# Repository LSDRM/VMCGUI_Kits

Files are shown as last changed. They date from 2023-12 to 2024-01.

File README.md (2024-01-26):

Resources for [VMCGUI](https://github.com/LSDRM/VMCGUI)
===============
----------
## Kits
### Arduino based :
No arduino based kit has been developed yet.

### Customized :
- [DualPressure - Thermocouple / through UART protocol](https://github.com/LSDRM/DualPressure-Thermocouple_forVMCGUI) : A DAQ board embeding two pressure sensors and one thermocouple. Developed by @B137P107

### Raspberry Pi based :
No raspberry pi based kit has been developed yet.

-------
## Modules
- [USB to UART bridge](https://github.com/LSDRM/USBtoUART-module_forVMCGUI) : To allow a computer the communicate through an UART communication line, via its USB port. Developed by @B137P107
--------

Make your own kit
=============
This repository include a _#BlankKit.py_ file which is a base to start making your own kit, working with VMCGUI. Making your own kit requires a bit of electronical knowledge, especially if you want to do it by making your own DAQ board (i.e. without an Arduino or other ready-to-use DAQ board). Creating a new kit implies software and hardware development, the both parts are described below.

Software development
-----------
You should only need to make a python kit file from the _#BlankKit.py_, without modifying any file from the source code of VMCGUI. The latter file need to be renamed with the name you want to give it, and placed in the "APP/Kits" folder of the VMCGUI repository. Note that the _#_ right before the name of your file set this kit as inactive, so  VMCGUI will ignore it.

At the top of your kit file, you should find the imported packages. This is where you can call new packages for your application. For example, you can call `import pyfirmata` if you know your kit is an Arduino-based one using an USB connection.

The first method of the main class contained in the kit file is the `__init__` one. In this class, you should find parameters for your kit as described below :
- `self.setWindowTitle()` : Put between the brackets the title of the window for your kit in string format.
- `self.prefix` : This parameter take a string, which gonna be placed right before the default name of the recorded files.
- `self.closeStartWindowOnLaunch` : Is set to `True` by default to prevent opening multiple times the same Kit Window, which risks to create conflict between multiple windows calling the same connection port.
- `self.graphTitle` : Is a list of strings containing the name of each sensor present with the DAQ board.
- `self.sensorsNumber` : Shall not be modified since it need to correspond the number of sensors name in `self.graphTitle`.
- `self.GPIOsNumber` : Take the number of accessible GPIOs on the DAQ board.

Hardware development
-----------
### Arduino

### Customized

### Raspberry Pi

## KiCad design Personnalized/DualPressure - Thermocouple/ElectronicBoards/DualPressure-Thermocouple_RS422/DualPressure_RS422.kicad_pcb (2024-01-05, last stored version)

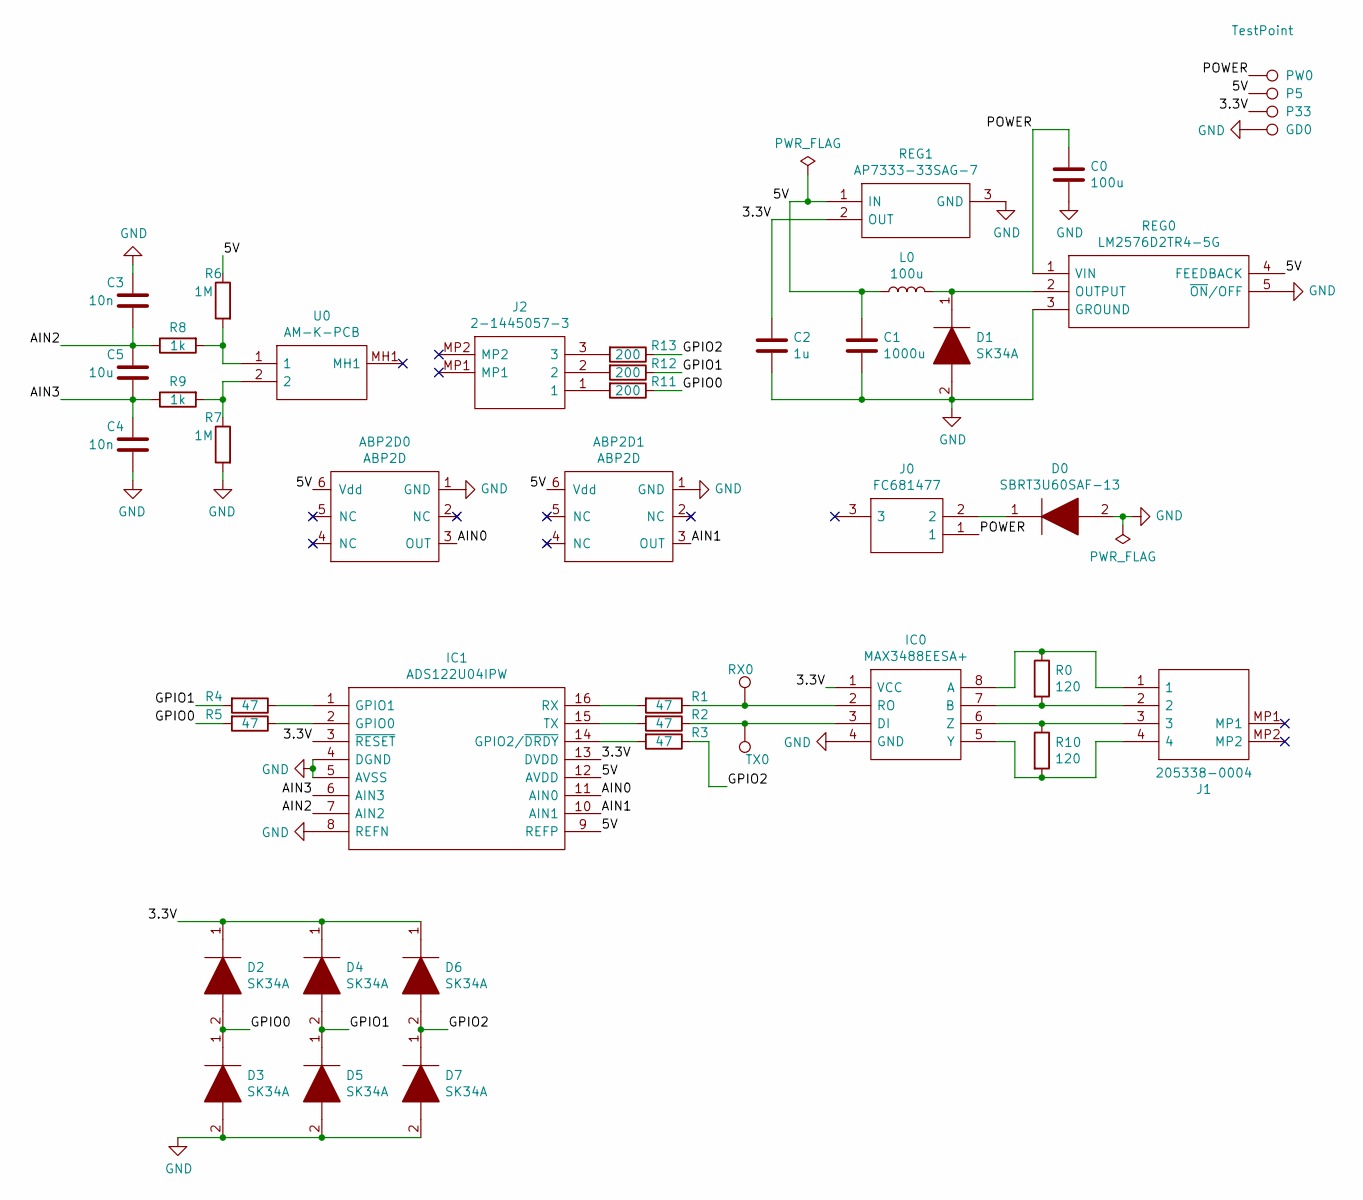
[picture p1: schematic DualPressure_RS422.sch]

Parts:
ABP2D0, ABP2D1: ABP2D
C0: 100u; CP_Elec_8x10.5
C1: 1000u; CP_Elec_10x10.5
C2: 1u; C_0603_1608Metric_Pad1.08x0.95mm_HandSolder
C3, C4: 10n; C_1206_3216Metric_Pad1.33x1.80mm_HandSolder
C5: 10u; C_1206_3216Metric_Pad1.33x1.80mm_HandSolder
D0: SBRT3U60SAF-13; SODFL5226X110N; Mouser Part Number 621-SBRT3U60SAF-13
D1, D2, D3, D4, D5, D6, D7: SK34A; DIOM5126X230N; Mouser Part Number 821-SK34A
GD0: TestPoint; TestPoint_THTPad_2.5x2.5mm_Drill1.2mm
IC0: MAX3488EESA+; SOIC127P600X175-8N; Mouser Part Number 700-MAX3488EESA
IC1: ADS122U04IPW; SOP65P640X120-16N; Mouser Part Number 595-ADS122U04IPW
J0: FC681477; Manufacturer_Part_Number FC681477
J1: 205338-0004; 2053380004; Manufacturer_Part_Number 205338-0004; Mouser Part Number 538-205338-0004
J2: 2-1445057-3; 214450573; Mouser Part Number 571-2-1445057-3
L0: 100u; L_0805_2012Metric_Pad1.15x1.40mm_HandSolder
P5, P33: TestPoint; TestPoint_THTPad_D2.5mm_Drill1.2mm
PW0: TestPoint; TestPoint_THTPad_D2.5mm_Drill1.2mm
R0, R10: 120; R_0805_2012Metric_Pad1.20x1.40mm_HandSolder
R1, R2, R3, R4, R5: 47; R_0805_2012Metric_Pad1.20x1.40mm_HandSolder
R6, R7: 1M; R_0805_2012Metric_Pad1.20x1.40mm_HandSolder
R8, R9: 1k; R_0805_2012Metric_Pad1.20x1.40mm_HandSolder
R11, R12, R13: 200; R_0805_2012Metric_Pad1.15x1.40mm_HandSolder
REG0: LM2576D2TR4-5G; D2TSUFFIX-CASE936A-02-ISSUEC; Mouser Part Number 863-LM2576D2TR4-5G
REG1: AP7333-33SAG-7; SOT96P240X135-3N; Mouser Part Number 621-AP7333-33SAG-7
RX0: TestPoint; TestPoint_THTPad_D2.5mm_Drill1.2mm
TX0: TestPoint; TestPoint_THTPad_D2.5mm_Drill1.2mm
U0: AM-K-PCB; AMKPCB; Manufacturer_Part_Number AM-K-PCB

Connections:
/3.3V: C2.1, D2.1, D4.1, D6.1, IC0.1 (VCC), IC1.3 (~RESET), IC1.13 (DVDD), P33.1, REG1.2 (OUT)
/5V: ABP2D0.6 (Vdd), ABP2D1.6 (Vdd), C1.1, IC1.9 (REFP), IC1.12 (AVDD), L0.1, P5.1, R6.1, REG0.4 (FEEDBACK), REG1.1 (IN)
/AIN0: ABP2D0.3 (OUT), IC1.11 (AIN0)
/AIN1: ABP2D1.3 (OUT), IC1.10 (AIN1)
/AIN2: C3.2, C5.1, IC1.7 (AIN2), R8.1
/AIN3: C4.1, C5.2, IC1.6 (AIN3), R9.1
/GPIO0: D2.2, D3.1, R5.2, R11.1
/GPIO1: D4.2, D5.1, R4.2, R12.1
/GPIO2: D6.2, D7.1, R3.1, R13.1
/POWER: C0.1, J0.1, PW0.1, REG0.1 (VIN)
GND: ABP2D0.1 (GND), ABP2D1.1 (GND), C0.2, C1.2, C2.2, C3.1, C4.2, D0.2, D1.2, D3.2, D5.2, D7.2, GD0.1, IC0.4 (GND), IC1.4 (DGND), IC1.5 (AVSS), IC1.8 (REFN), R7.2, REG0.3 (GROUND), REG0.5 (~ON~/OFF), REG0.6, REG1.3 (GND)
unnamed: D0.1, J0.2
unnamed: D1.1, L0.2, REG0.2 (OUTPUT)
unnamed: IC0.2 (RO), R1.1, RX0.1
unnamed: IC0.3 (DI), R2.1, TX0.1
unnamed: IC0.5 (Y), J1.4, R10.2
unnamed: IC0.6 (Z), J1.3, R10.1
unnamed: IC0.7 (B), J1.2, R0.2
unnamed: IC0.8 (A), J1.1, R0.1
unnamed: IC1.1 (GPIO1), R4.1
unnamed: IC1.2 (GPIO0), R5.1
unnamed: IC1.14 (GPIO2/~DRDY), R3.2
unnamed: IC1.15 (TX), R2.2
unnamed: IC1.16 (RX), R1.2
unnamed: J2.1, R11.2
unnamed: J2.2, R12.2
unnamed: J2.3, R13.2
unnamed: R6.2, R8.2, U0.1
unnamed: R7.1, R9.2, U0.2

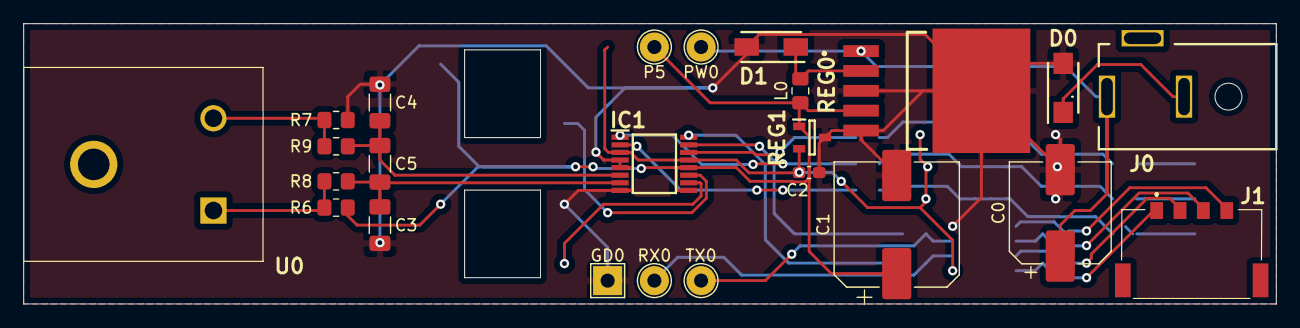
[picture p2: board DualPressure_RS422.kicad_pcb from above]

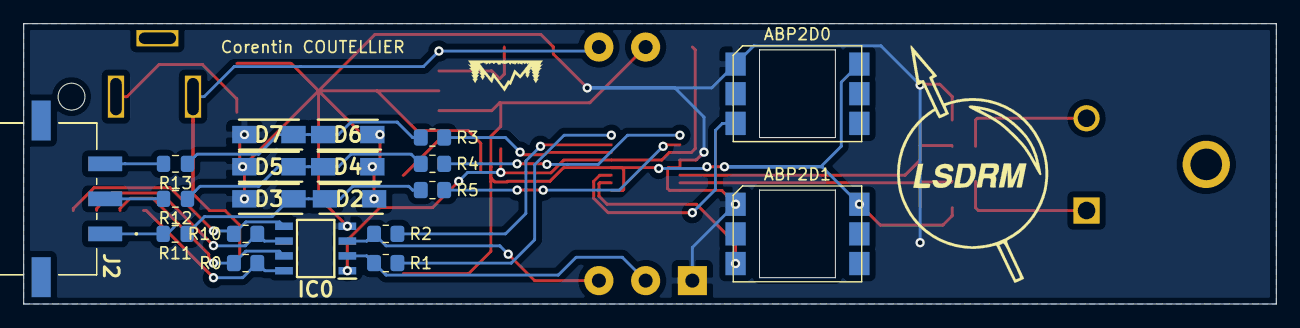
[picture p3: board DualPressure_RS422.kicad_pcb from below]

Board: 2 copper layers, 107.2 x 24.0 mm, 44 parts (20 on the bottom side), 29 nets.

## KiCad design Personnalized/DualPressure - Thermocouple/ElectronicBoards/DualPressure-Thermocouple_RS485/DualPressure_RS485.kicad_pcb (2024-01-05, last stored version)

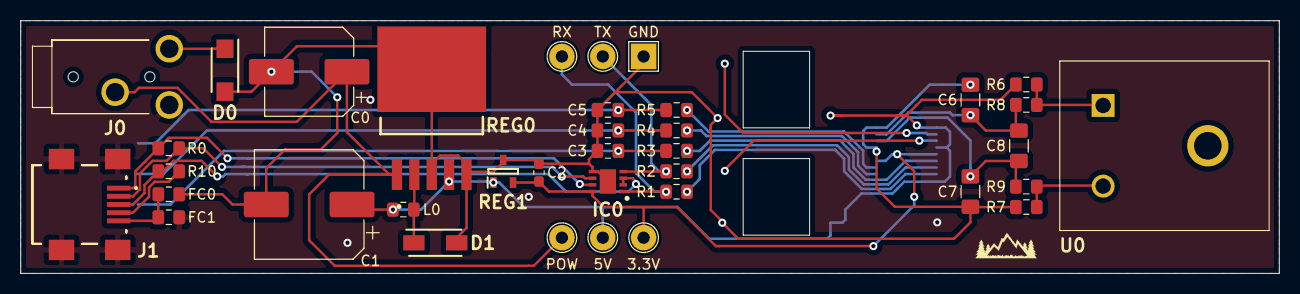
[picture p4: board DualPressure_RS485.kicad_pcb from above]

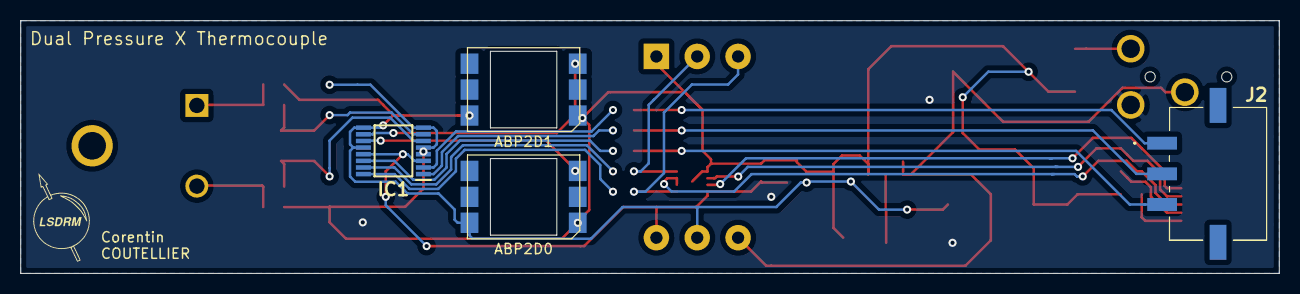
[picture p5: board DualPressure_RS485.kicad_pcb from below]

Board: 2 copper layers, 123.2 x 24.8 mm, 41 parts (4 on the bottom side), 28 nets.

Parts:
3.3V, 5V: TestPoint; TestPoint_THTPad_D2.5mm_Drill1.2mm
ABP2D0, ABP2D1: ABP2D
C0: 100u; CP_Elec_8x10.5
C1: 1000u; CP_Elec_10x10.5
C2: 1u; C_0603_1608Metric_Pad1.05x0.95mm_HandSolder
C3: FREECHOICE; C_0805_2012Metric_Pad1.15x1.40mm_HandSolder
C4, C5: FC; C_0805_2012Metric_Pad1.15x1.40mm_HandSolder
C6, C7: 10n; C_1206_3216Metric_Pad1.42x1.75mm_HandSolder
C8: 10u; C_1206_3216Metric_Pad1.42x1.75mm_HandSolder
D0: SBRT3U60SAF-13; SODFL5226X110N
D1: SK34A; DIOM5126X230N
FC0, FC1: R; R_0805_2012Metric_Pad1.15x1.40mm_HandSolder
GND: TestPoint; TestPoint_THTPad_2.5x2.5mm_Drill1.2mm
IC0: MAX14840EATA+; SON65P300X300X80-9N
IC1: ADS122U04IPW; SOP65P640X120-16N
J0: STX-3000; STX3000
J1: USB2066-05-RBHM-15-STB-00-00-A; USB206605RBHM15STB0000A
J2: 2-1445057-3; 214450573
L0: 100u; L_0805_2012Metric_Pad1.15x1.40mm_HandSolder
POW: TestPoint; TestPoint_THTPad_D2.5mm_Drill1.2mm
R0, R10: 120; R_0805_2012Metric_Pad1.15x1.40mm_HandSolder
R1, R2, R3, R4, R5: 47; R_0805_2012Metric_Pad1.15x1.40mm_HandSolder
R6, R7: 1M; R_0805_2012Metric_Pad1.15x1.40mm_HandSolder
R8, R9: 1k; R_0805_2012Metric_Pad1.15x1.40mm_HandSolder
REG0: LM2576D2TR4-5G; D2TSUFFIX-CASE936A-02-ISSUEC
REG1: AP7333-33SAG-7; SOT96P240X135-3N
RX: TestPoint; TestPoint_THTPad_D2.5mm_Drill1.2mm
TX: TestPoint; TestPoint_THTPad_D2.5mm_Drill1.2mm
U0: AM-K-PCB; AMKPCB

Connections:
/3.3V: 3.3V.1, C2.1, IC0.8, IC1.3, IC1.13, REG1.2
/5V: 5V.1, ABP2D0.6, ABP2D1.6, C1.1, IC1.9, IC1.12, L0.1, R6.1, REG0.4, REG1.1
/#ENABLE: IC0.2, IC0.3, J1.3, R10.1
/AIN0: ABP2D0.3, IC1.11
/AIN1: ABP2D1.3, IC1.10
/AIN2: C6.2, C8.1, IC1.7, R8.1
/AIN3: C7.1, C8.2, IC1.6, R9.1
/ENABLE: J1.4, R10.2
/GPIO0: C5.1, J2.1, R5.2
/GPIO1: C4.1, J2.2, R4.2
/GPIO2: C3.1, J2.3, R3.1
/POWER: C0.1, J0.1, POW.1, REG0.1
/SHIELD: FC1.2, J0.3, J1.MP1, J1.MP2, J1.MP3, J1.MP4
GND: ABP2D0.1, ABP2D1.1, C0.2, C1.2, C2.2, C3.2, C4.2, C5.2, C6.1, C7.2, D0.2, D1.2, FC0.2, GND.1, IC0.5, IC0.9, IC1.4, IC1.5, IC1.8, R7.2, REG0.3, REG0.5, REG0.6, REG1.3
unnamed: D0.1, J0.2
unnamed: D1.1, L0.2, REG0.2
unnamed: FC0.1, FC1.1, J1.5
unnamed: IC0.1, R1.1, RX.1
unnamed: IC0.4, R2.1, TX.1
unnamed: IC0.6, J1.2, R0.2
unnamed: IC0.7, J1.1, R0.1
unnamed: IC1.1, R4.1
unnamed: IC1.2, R5.1
unnamed: IC1.14, R3.2
unnamed: IC1.15, R2.2
unnamed: IC1.16, R1.2
unnamed: R6.2, R8.2, U0.1
unnamed: R7.1, R9.2, U0.2

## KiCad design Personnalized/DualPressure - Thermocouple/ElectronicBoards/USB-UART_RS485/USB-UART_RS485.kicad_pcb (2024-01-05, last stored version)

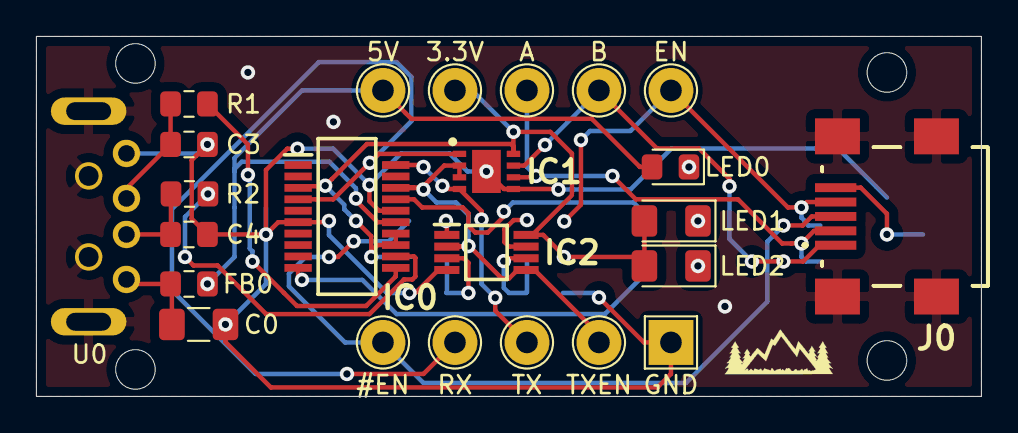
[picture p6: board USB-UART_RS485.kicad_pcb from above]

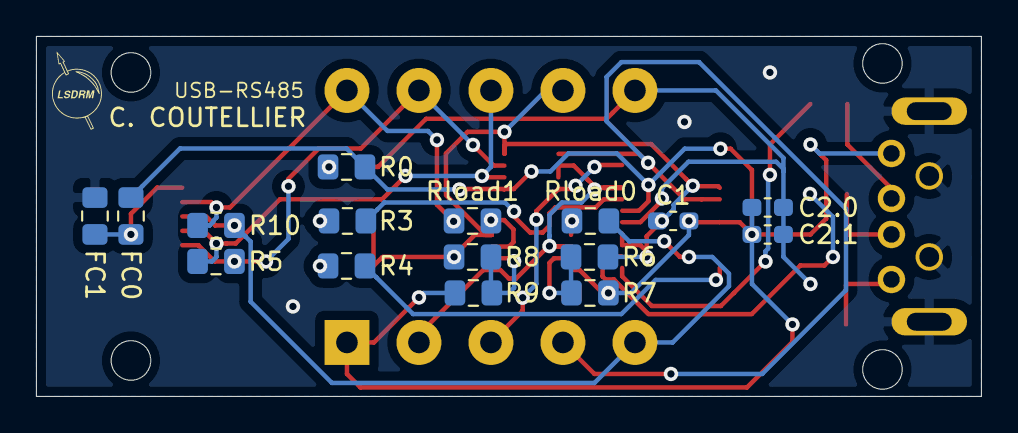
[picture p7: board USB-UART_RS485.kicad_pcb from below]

Board: 2 copper layers, 52.5 x 20.0 mm, 39 parts (16 on the bottom side), 26 nets.

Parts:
3.3V, 5V: TestPoint; TestPoint_THTPad_D2.5mm_Drill1.2mm
A: TestPoint; TestPoint_THTPad_D2.5mm_Drill1.2mm
B: TestPoint; TestPoint_THTPad_D2.5mm_Drill1.2mm
C0: 10n; C_1206_3216Metric_Pad1.42x1.75mm_HandSolder
C1, C2.1: 0.1u; C_0603_1608Metric_Pad1.05x0.95mm_HandSolder
C2.0: 4.7u; C_0603_1608Metric_Pad1.05x0.95mm_HandSolder
C3, C4: 47p; C_0805_2012Metric_Pad1.15x1.40mm_HandSolder
EN: TestPoint; TestPoint_THTPad_D2.5mm_Drill1.2mm
FB0: Ferrite_Bead_Small; L_0805_2012Metric_Pad1.15x1.40mm_HandSolder
FC0, FC1: R; R_0805_2012Metric_Pad1.15x1.40mm_HandSolder
GND: TestPoint; TestPoint_THTPad_2.5x2.5mm_Drill1.2mm
IC0: FT231XS-R; SOP64P599X175-20N
IC1: MAX14840EATA+; SON65P300X300X80-9N
IC2: NCS20032DMR2G; SOP65P490X110-8N
J0: USB2066-05-RBHM-15-STB-00-00-A; USB206605RBHM15STB0000A
LED0: LG R971; LED_0805_2012Metric_Pad1.15x1.40mm_HandSolder
LED1, LED2: KP-3216SURC; LED_1206_3216Metric_Pad1.42x1.75mm_HandSolder
R0: 130; R_0805_2012Metric_Pad1.15x1.40mm_HandSolder
R1, R2: 27; R_0805_2012Metric_Pad1.15x1.40mm_HandSolder
R3, R4: 68; R_0805_2012Metric_Pad1.15x1.40mm_HandSolder
R5, R10: 120; R_0805_2012Metric_Pad1.15x1.40mm_HandSolder
R6, R7, R8, R9: 1M; R_0805_2012Metric_Pad1.15x1.40mm_HandSolder
RX: TestPoint; TestPoint_THTPad_D2.5mm_Drill1.2mm
Rload0, Rload1: 10k; R_0805_2012Metric_Pad1.15x1.40mm_HandSolder
TX: TestPoint; TestPoint_THTPad_D2.5mm_Drill1.2mm
TXEN: TestPoint; TestPoint_THTPad_D2.5mm_Drill1.2mm
U0: MC32603

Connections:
/3.3V: 3.3V.1, C1.1, IC0.3, IC0.13, IC0.14, IC1.8, IC2.8, LED1.2, LED2.2, R6.2, R8.1
/5V: 5V.1, C2.0.1, C2.1.1, FB0.1, IC0.15, LED0.2
/#ENABLE: J0.3, R10.1, Rload0.2
/D+: C3.2, R1.2, U0.3
/D-: C4.1, R2.2, U0.2
/ENABLE: EN.1, J0.4, R10.2, Rload1.1
/SHIELD: FC1.2, J0.MP1, J0.MP2, J0.MP3, J0.MP4, U0.5
/TXDEN: IC0.18, IC1.2, IC1.3, IC2.2, IC2.5, TXEN.1
GND: C0.2, C1.2, C2.0.2, C2.1.2, C3.1, C4.2, FC0.2, GND.1, IC0.6, IC0.16, IC1.5, IC1.9, IC2.4, R0.1, R7.2, R9.2, U0.4
unnamed: A.1, IC1.6, J0.2, R5.2
unnamed: B.1, IC1.7, J0.1, R5.1
unnamed: C0.1, FB0.2, U0.1
unnamed: FC0.1, FC1.1, J0.5
unnamed: IC0.4, IC1.1, RX.1
unnamed: IC0.10, R4.1
unnamed: IC0.11, R1.1
unnamed: IC0.12, R2.1
unnamed: IC0.17, R3.1
unnamed: IC0.20, IC1.4, TX.1
unnamed: IC2.1, Rload0.1
unnamed: IC2.3, R6.1, R7.1
unnamed: IC2.6, R8.2, R9.1
unnamed: IC2.7, Rload1.2
unnamed: LED0.1, R0.2
unnamed: LED1.1, R3.2
unnamed: LED2.1, R4.2
